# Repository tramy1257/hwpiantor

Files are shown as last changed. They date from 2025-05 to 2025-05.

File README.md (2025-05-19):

# hwpiantor

_3D Printed, Handwired, Piantor Style Keyboard_
<p float="left">
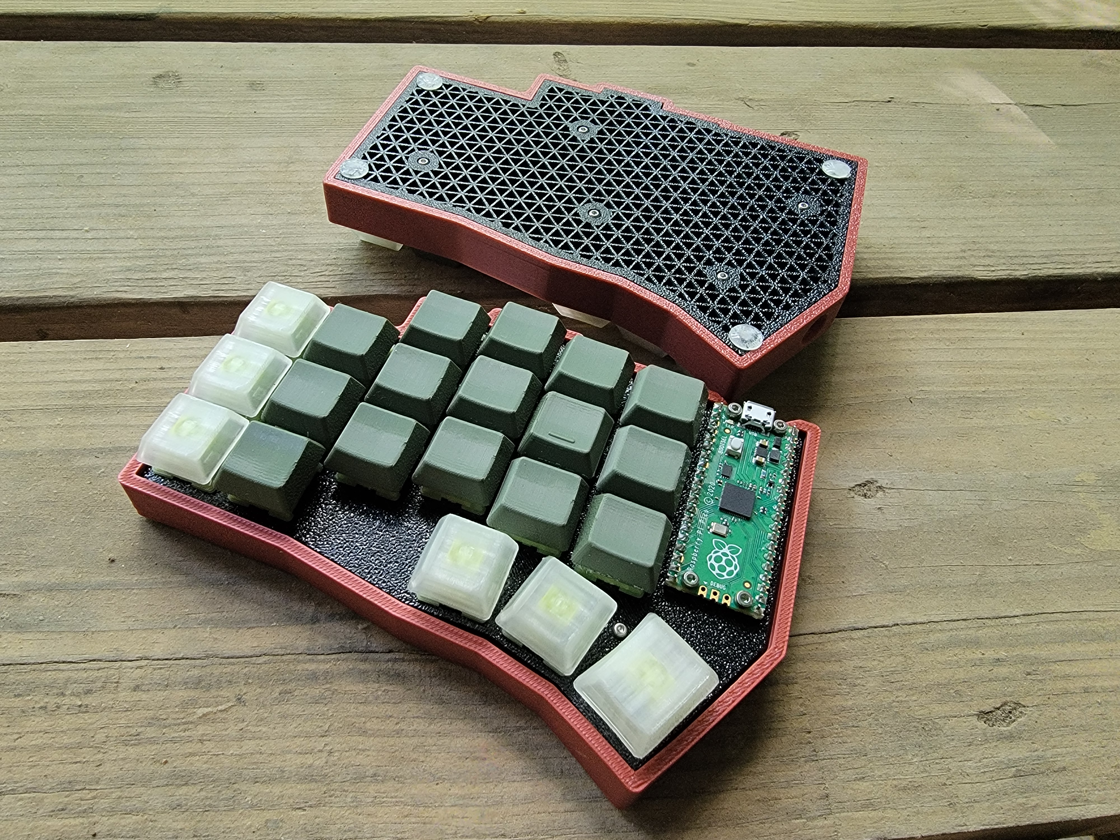
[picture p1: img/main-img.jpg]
  
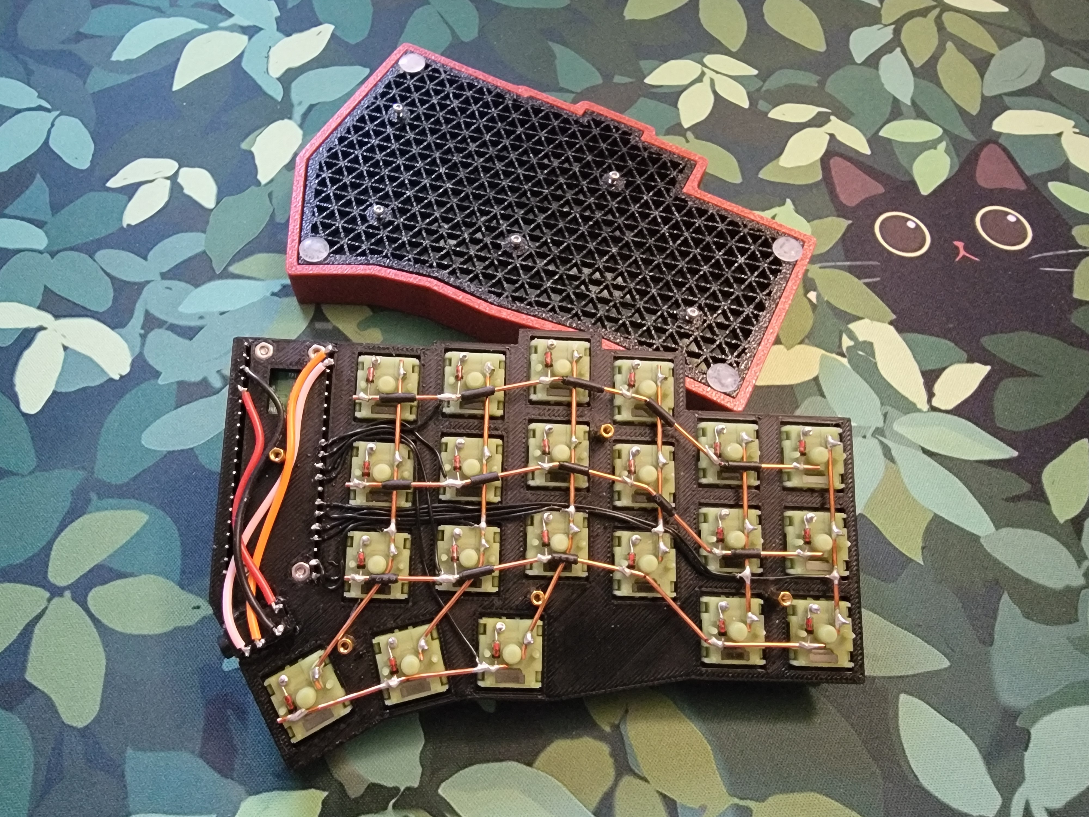
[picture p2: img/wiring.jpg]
  
</p>

## Overview
I made this keyboard to tryout the Piantor/Cantor layout with parts I already have at home.

The goal is to show off as much DIY elements as possible. Eventually, the back cover will be replaced with a clear acrylic cover to show off the wiring.

## BOM
* 42 x MX Switches
* 42 x diodes
* 5 x 6mm M2 standoffs
* 10 x 5mm M2 button head screws*
* 4 x M2 nuts
* 4 x 6mm M2 button head screws**
* 2x Raspberry Pi Pico or Pico 2
* 2 x TRRS sockets
* Rubber feets (Optional)

**Socket head screws work as well. They have higher heads, which will stick out of the bottom of the case. But if you're using rubber feets, it should not be a problem.*

***Any screw length from 6mm to 12mm should work. Button head screws work fine here.*

## Building

### I. 3D Printing
[Printing the case and plate](./printing/README.md)

[Printed keycaps by Joe Scotto](https://github.com/joe-scotto/scottokeebs/tree/main/Extras/ScottoCaps/Scooped/MX)

### II. Preparing the plate for soldering
Screw the **6mm standoffs** to the underside of the plate with **5mm M2 screws**

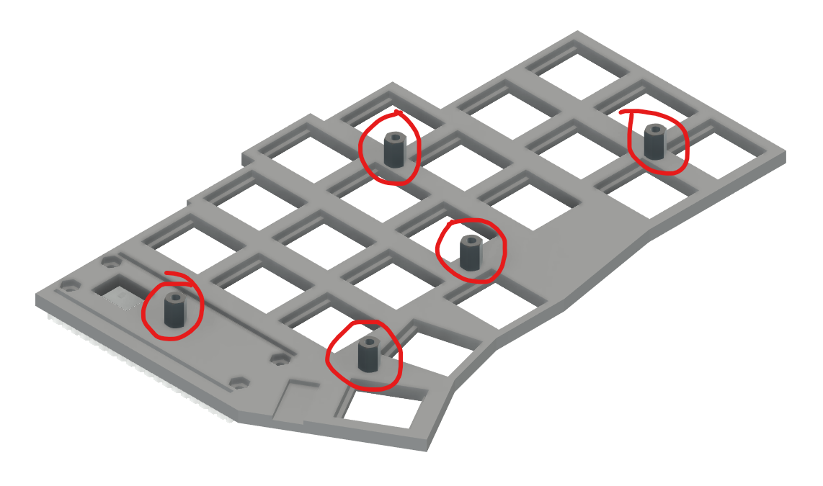
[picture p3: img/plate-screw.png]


Add the **M2 nuts** to the underside of the plate for securing the Pi Pico

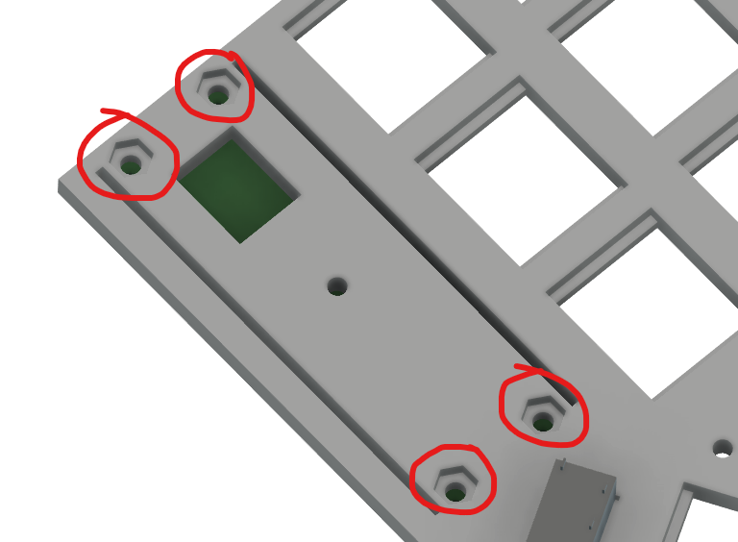
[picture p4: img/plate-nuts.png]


Solder the pin headrs to the Pi Pico. Then screw the Pi Pico to the plate with **6mm M2 screws** (Any screw length from 6mm to 12mm should work). The pin headers legs should stick through the 2 tracks on the plate

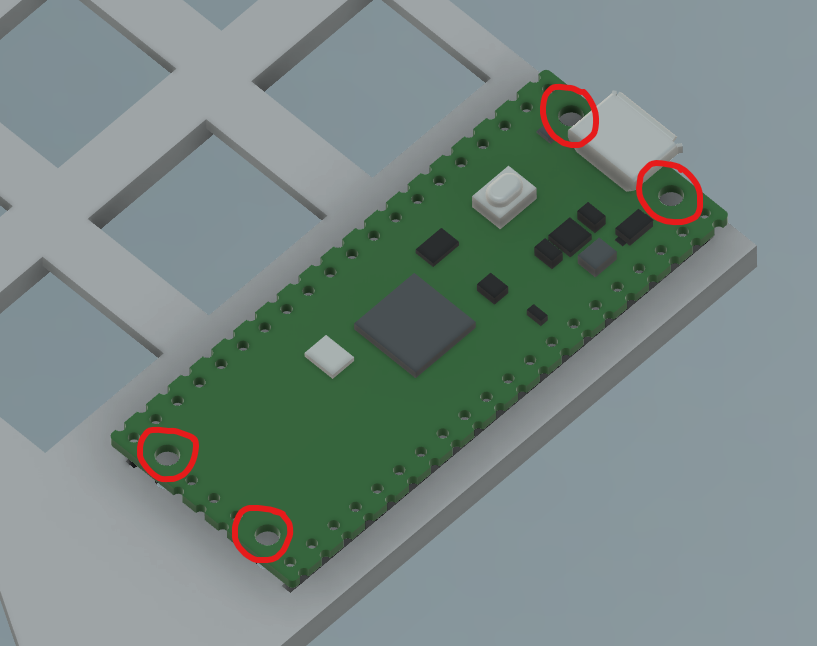
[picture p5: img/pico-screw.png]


Glue the TRRS socket to the plate.

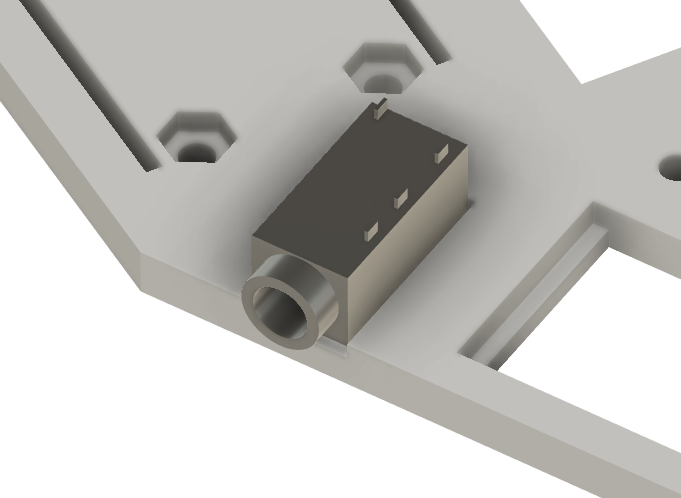
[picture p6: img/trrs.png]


### III. Soldering the switches and the Pico
Checkout [Joe Scotto's video on how to handwire a keyboard](https://www.youtube.com/watch?v=hjml-K-pV4E) if you don't know how wiring work yet.

This is how my switches are wired. If you choose to use different pins, make sure you update them in the firmware file later.

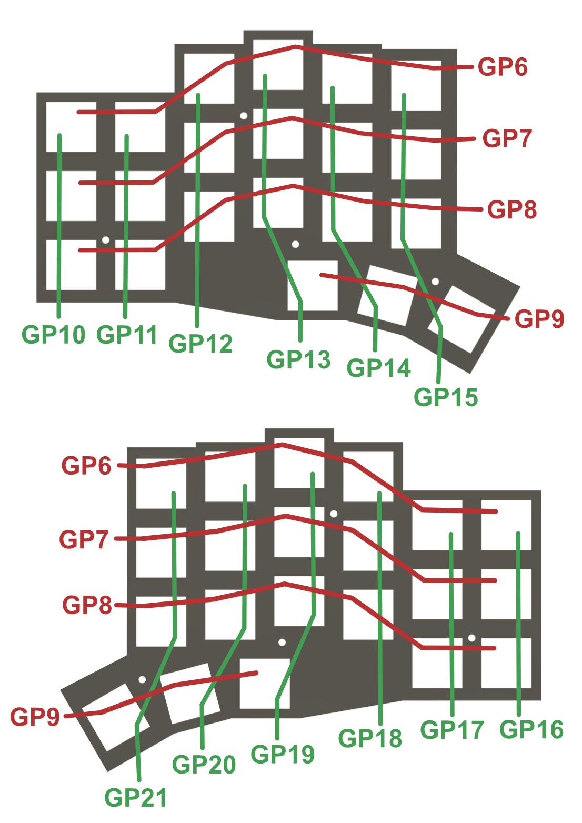
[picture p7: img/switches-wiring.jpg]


To connect the 2 Pi Picos, follow this wiring diagram. It does not matter which pin on the TRRS socket you wire the Pico's pins to. Both sides wiring just need to match exactly. Once you're done soldering both TRRS sockets, it is a good idea to connect the halves and check the Picos' pins continuity with a multimeter.

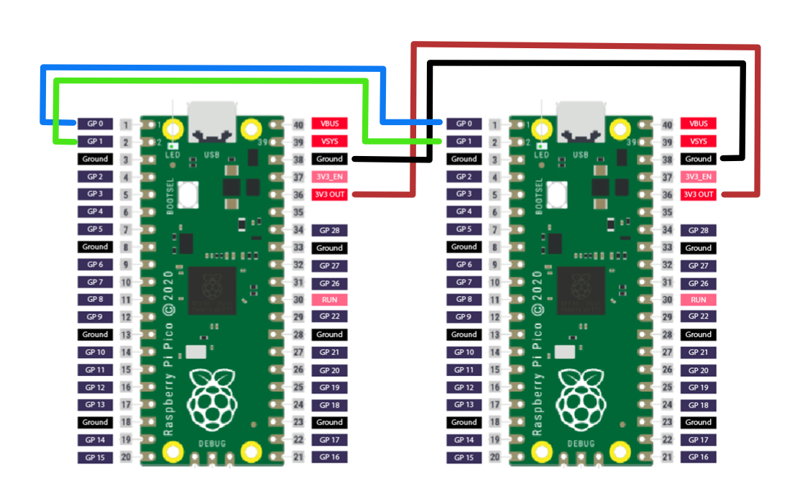
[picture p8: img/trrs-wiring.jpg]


### IV. Assembling the keyboard
Finally, screw the plate and the case together using **5mm M2 screws**

## Firmware
I used KMK firmware configured with [Pog](https://pog.janlunge.de/) v2.0.4. I have not had a chance to test the firmware on a different keyboard yet, but here's how to install the firmware:

### KMK only
1. Install KMK Firmware on both Picos: [KMK > Getting Started](https://github.com/KMKfw/kmk_firmware/blob/main/docs/en/Getting_Started.md)
2. Rename the left Pico drive to PIANTORHWL and the right Pico drive to PIANTORHWR
2. Copy the files in [kmk-firmware > left](./kmk-firmware/left/) to the left Pico and [kmk-firmware > right](./kmk-firmware/right/) to the right Pico.
3. Make sure you update:
    1. The row and column pins in both **pog.json** files if you have different wiring
    2. The keymaps in the right **pog.json** file for different keymap
1. The keyboard should work now but configuring keymaps without Pog can be tedious

### Using Pog
Using Pog will let you remap you keys easier. NOTE: I used Pog v2.0.4 so it may not work for future Pog versions
1. Follow the same steps above.
3. Connect the right half to the computer
2. Install [Pog](https://pog.janlunge.de/) on your computer
1. Open Pog > Add Keyboard > Add Existing Pog Keyboard > Select the pog.json file for the right Pico drive
1. You can then configure the keyboard layout, row and column pins using Pog

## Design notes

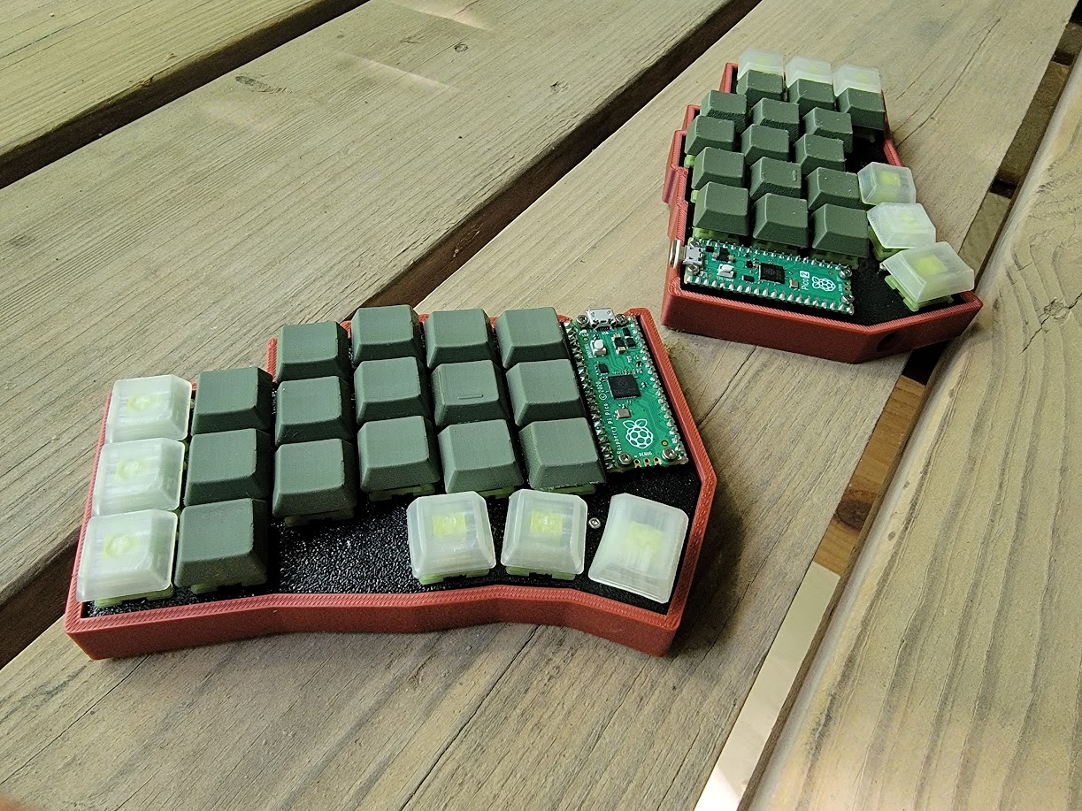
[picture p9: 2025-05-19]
img/both-side.jpg

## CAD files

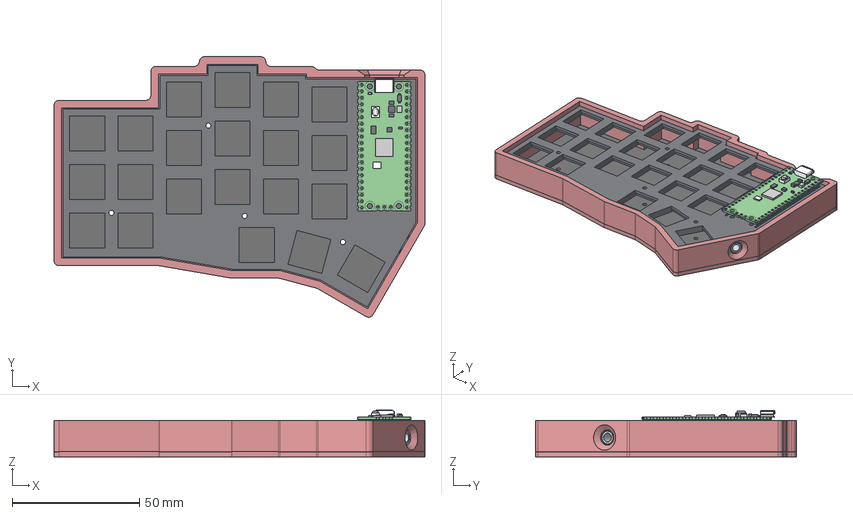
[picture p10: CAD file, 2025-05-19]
printing/hwpiantor.step
145.9 x 102.5 x 18.3 mm
plate
PICO_REF_BOARD
PICO_REF_COMP_3
PICO_REF_COMP_4
PICO_REF_COMP_5
PICO_REF_COMP_6
PICO_REF_COMP_2
PICO_REF_COMP_3_1
PICO_REF_USB
PICO_REF_SWITCH
PICO_REF_MICROCONTROLLER
PICO_REF_COMP_1
PICO_REF_LED
PICO_REF_COMP_7
PICO_REF_INDUCTOR
case-bottom-printed
case-wall
trrs-socket
case

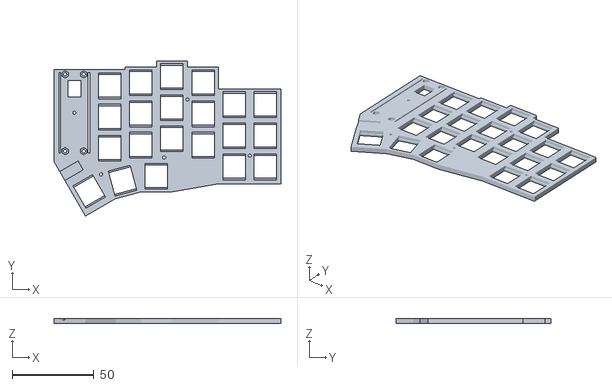
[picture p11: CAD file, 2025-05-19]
printing/stl/plate.stl
138.9 x 94.9 x 3.00

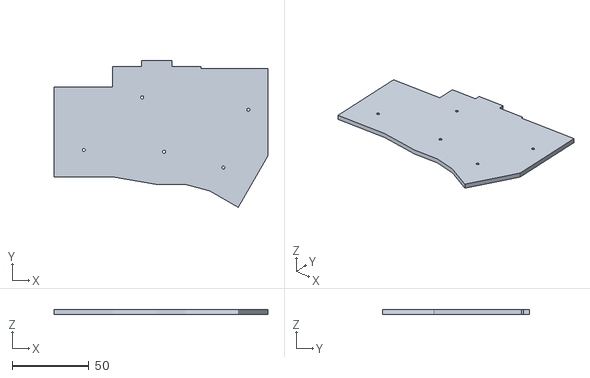
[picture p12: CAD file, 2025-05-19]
printing/stl/case-2-part-bottom.stl
139.5 x 95.6 x 3.00

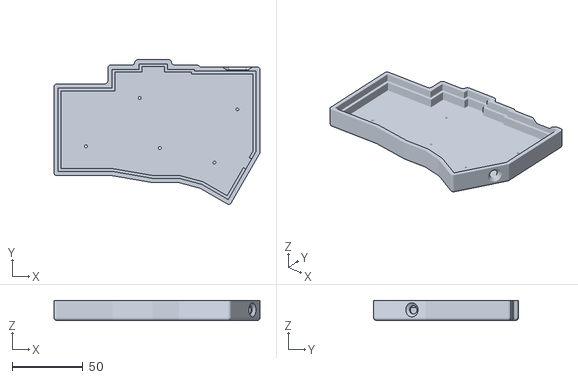
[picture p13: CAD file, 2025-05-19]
printing/stl/case-1-part.stl
145.9 x 102.5 x 14.2

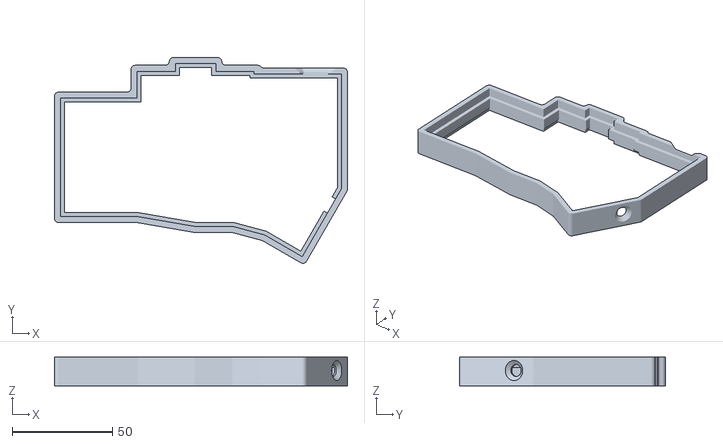
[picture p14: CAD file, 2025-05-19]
printing/stl/case-2-part-wall.stl
145.9 x 102.5 x 14.2

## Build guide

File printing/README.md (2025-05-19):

# 3D Printing Notes
All STLs are for the left side of the keyboard. Simply flip them in the slicer to print the right side

## Case
There are 2 case designs:
1. Single part case (case-1-part.stl) - No support needed
2. Two-part case - Designed so the bottom cover can be switched to a clear cover down the line
    - case-2-part-wall.stl - Needs support for top ledge or bottom ledge (default orientation). I use PETG interface layer for support with great result.

## Bottom Cover
Use the two-part case for customizable bottom cover.

To print the meshed cover like I did, update the slicing settings:
- Wall loops: 4
- Top layer: 0
- Bottom layer: 0
- Infill pattern: Whichever connected pattern that you like
- Infill density: Depends on the pattern. I set 30% for Triangles pattern

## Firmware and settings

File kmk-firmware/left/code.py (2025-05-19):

# Main Keyboard Configuration - v1.0.0
import board
import pog
# check if we just want to run the coord_mappping Assistant
if pog.coordMappingAssistant:
    from coordmaphelper import CoordMapKeyboard
    if __name__ == '__main__':
        CoordMapKeyboard().go()
    print("Exiting Coord Mapping Assistant Because of an error")
else:
    from kb import POGKeyboard
    # set the required features for you keyboard and keymap
    # add custom ones in the kb.py

    keyboard = POGKeyboard(features=pog.kbFeatures)

    # manage settings for our modules and extensions here
    keyboard.tapdance.tap_time = 200

    # Keymap
    import keymap
    keyboard.keymap = keymap.keymap

    # Encoder Keymap if available
    if pog.hasEncoders:
        keyboard.encoder_handler.map = keymap.encoderKeymap

    # Execute the keyboard loop
    if __name__ == '__main__':
        keyboard.go()

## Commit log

2025-05-19 Added firmware and model files
    [case-1-part.stl, case-2-part-bottom.stl, case-2-part-wall.stl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]
2025-05-19 Fix trrs wiring diagram and README images
2025-05-19 Fix wiring diagram
